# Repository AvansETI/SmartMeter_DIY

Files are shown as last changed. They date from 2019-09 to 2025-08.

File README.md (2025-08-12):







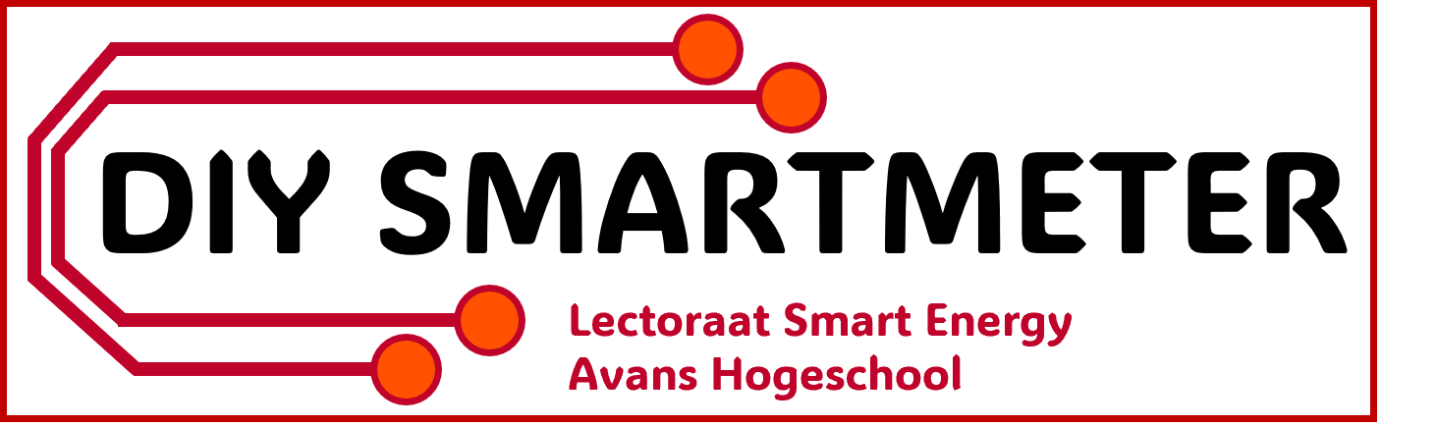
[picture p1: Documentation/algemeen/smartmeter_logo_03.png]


Bij het lectoraat Smart Energy, onderdeel van het Centre of Expertise Materialen en Energietransitie (MNEXT) van Avans Hogeschool te Breda, is een goedkoop en eenvoudig in elkaar te zetten do-it-yourself (DIY) kit(je) ontwikkeld, waarmee de slimme energiemeter thuis kan worden uitgelezen. Het kitje bestaat uit een printplaat, een minicomputer en wat losse elektronicacomponenten. Het in elkaar solderen, configureren en thuis aansluiten op de slimme energiemeter is een eenvoudige klus.

Dit inititief is ontstaan binnen de onderzoekslijn Meten & Weten. Het is belangrijk om meer inzicht te krijgen in het energieverbruik van het eigen huishouden. Door dit kitje kunnen consumenten en bedrijven inzicht krijgen in hun eigen energieverbruik.

Het doel van dit project is informatie te verzamelen van  veel aangesloten slimme meters ter ondersteuning van onderzoek en onderwijs. Alle verzamelde informatie is  moeilijk herleidbaar tot personen en/of locaties. De verzamelde informatie is openbaar om de energietransitie te ondersteunen.

Doe jij ook mee?

## Quick start
Heb je jouw DIY Smartmeter kitje al bemachtigd? Kijk dan op de [wiki](https://github.com/AvansETI/SmartMeter_DIY/wiki). Hier kan je de bouwhandleiding vinden voor het solderen van de printplaat én het uploaden van de firmware. Neem contact op met het lectoraat om in bezit te komen van dit gave kitje. Zie hieronder wat belangrijke links die je kan gebruiken.

* Wiki: [https://github.com/AvansETI/SmartMeter_DIY/wiki](https://github.com/AvansETI/SmartMeter_DIY/wiki)
* Source: [https://github.com/AvansETI/SmartMeter_DIY](https://github.com/AvansETI/SmartMeter_DIY)
* Lectoraat Smart Energy: [https://www.avans.nl/onderzoek/expertisecentra/mnext/lectoraten/smart-energy](https://www.avans.nl/onderzoek/expertisecentra/mnext/lectoraten/smart-energy)

## Meedoen
Niet alleen wij hebben goede ideeën. Jij kan ook meedoen. Heb je een leuk idee dan kan je dat via de issues dat kenbaar maken. Aan zowel de hardware en software kan je werken. Voor meer informatie zie [wiki](https://github.com/AvansETI/SmartMeter_DIY/wiki/8.-Contribute-to-the-software).

## Licentie
Alle documenten, hardware, software en documentatie zijn beschikbaar onder de [MIT-licentie](LICENSE.txt).

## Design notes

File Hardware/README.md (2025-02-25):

# SmartMeter Hardware

This directory contains all the versions we have created for this project. The hardware
is designed using KiCAD (https://www.kicad.org/) and the whole project is put on Git. It
is also possible to use the gerber files only to create your own version of the SmartMeter.

## Requirements

The hardware has been created with the following requirements:
1. It needs to be soldered by everyone!
2. All components should be through-the-whole.
3. The hardware will be provided as do-it-yourself kit.
4. It should support different type of SmartMeters P1-port with varying versions.

## Version 1

The first version of the SmartMeter. It contains some errors that neede to be fixed.

## Version 2

The second version fixed the errors.

## Version 2.1

This version supports the newest SmartMeter version. With this version is it possible to use
5V power from the SmartMeter. No need anymore to use an adapter. Furthermore, if you have an
electric vehicle, it can be connected to the hardware as well.

## Some notes

Make sure you use the newest version if you create your own version.

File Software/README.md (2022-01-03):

# SmartMeter Software

You can find here the firmware for the SmartMeter project. It uses a Wemos D1 mini lite
(https://www.wemos.cc/en/latest/d1/d1_mini_lite.html). Note that only the last version is
available that is used by the hardware version 2 and 3.

## sm-esp8266

This software is created using the Arduino IDE (https://www.arduino.cc/en/software). After
installing the IDE you need to add the ESP8266 boards. You can find a tutorial here: 
https://siytek.com/wemos-d1-mini-arduino-wifi/. Furthermore, you need to install some 
libraries:
- Install library WiFiManager by tablatronics: https://github.com/tzapu/WiFiManager
- Install library JsonArduino by Banoit Blanchon: https://arduinojson.org/?utm_source=meta&utm_medium=library.properties

when you are finished, you can compile and upload the sketch. In the case, you like more functionality
you can create the software yourself. We appreciate contribution by pull requests! You can become
part of the project as well.

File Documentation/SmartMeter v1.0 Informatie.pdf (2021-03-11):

## Expertisecentrum Technische Innovatie

## Lectoraat Smart Energy

# SMARTMETER

https://github.com/AvansETI/SmartMeter_DIY

Bij het Expertisecentrum Technische Innovatie (ETI) van Avans Hogeschool te Breda is een goedkope en makkelijk in elkaar te zetten do-it-yourself (DIY) kit(je) ontwikkeld waarmee de slimme energiemeter thuis kan worden uitgelezen. Het kitje bestaat uit een printplaat, een minicomputer en wat losse elektronica componenten. Het in elkaar solderen, configureren en thuis aansluiten op de slimme meter is een eenvoudige klus.

Het doel van dit alles is informatie uit veel aangesloten slimme meters te verzamelen. Deze informatie kan dan worden gebruikt in onderzoek en onderwijs. Alle verzamelde informatie is heel, heel moeilijk herleidbaar tot personen en/of locaties, hierover later meer. Alle verzamelde informatie is openbaar.

Avans Hogeschool en ETI nodigen iedereen uit om mee te doen in dit experiment. Voor de bouwhandleiding klik hier. (https://github.com/AvansETI/SmartMeter_DIY/wiki/Bouwhandleiding-van-de-DIY-Smart-Meter-kit)

SmartMeter specificatie
- Wemos D1 mini pro
- Smartmeter P1 interface
- Makkelijk te solderen

Werking
Het printplaatje is niets anders dan een interface die aangesloten wordt op de datapoort van een slimme meter. Deze poort heet ook wel de P1 poort. De minicomputer op het printplaatje zet P1 poort informatie om naar een internetprotocol. Bij Avans Hogeschool wordt deze

informatie in een database opgeslagen. De
minicomputer | is | met | het | internet
verbonden via de draadloze WiFi thuis.

Het printplaatje wordt gevoed met een standaard telefoonoplader. Het printplaatje wordt op de slimme meter aangesloten met
een | standaard | (ouderwetse) | vaste-
telefoon-kabeltje.

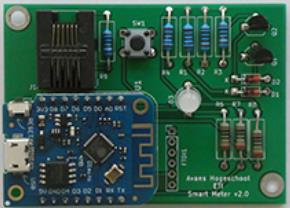
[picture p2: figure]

De informatie uit de P1 poort bevat
informatie | over | het | elektriciteit- | en
(meestal) aardgasverbruik. Oudere meters verversen deze infomatie elke 10 seconden,
recentere | meters | elke | seconde. | Het
printplaatje beperkt dit tot 1 bericht per 30 seconden. Per dag wordt ongeveer 2.5 Mbyte aan data verstuurd, dit is te vergelijken met een lage resolutie foto of een mp3 song.

Data
Elke minicomputer heeft een uniek nummer (Avans noemt dit een signature), Avans kan en wil dit nummer niet (vooraf) weten! De informatie uit jouw slimme meter is van jou maar door deze te delen kunnen studenten aan slimme toepassingen werken. De informatie uit de slimme meter wordt samengevoegd met het unieke nummer en verstuurd naar de Avans database. De verzonden informatie ziet er als volgt uit:

{"datagram": {
"p1": "/XMX5LGBBF...05FD\r\n",

"s1": {
"unit": "W",
"value": 0 },
"signature": "00000000d926eb43", "s0": {
"unit": "W",
"value": 0 } }
}

Onderwijs
Studenten gebruiken de SmartMeter om
een | Internet-ofThings | applicatie | te
realiseren. Hierbij wordt software voor de SmartMeter ontwikkeld, maar ook een back-end, database en front-end.

Onderzoek
Met de SmartMeter is het mogelijk op een
eenvoudige | wijze | gegevens | uit | een
smartmeter te halen en door te sturen naar
een | centrale | database. | Binnen | de
onderzoeken van het expertisecentrum wordt deze hardware gebruikt.

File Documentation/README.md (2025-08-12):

# Documentatie
De documentatie van de DIY Smartmeter kan je vinden op de [wiki](https://github.com/AvansETI/SmartMeter_DIY/wiki). Deze directory bevat alle bestanden en plaatjes die nodig zijn voor de wiki of andere markdown bestanden.

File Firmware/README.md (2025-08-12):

# SmartMeter Software

You can find here the firmware for the SmartMeter project. It uses a Wemos D1 mini lite
(https://www.wemos.cc/en/latest/d1/d1_mini_lite.html). Note that only the last version is
available that is used by the hardware version 2.0 and 2.1.

## ArduinoSketch / sm-esp8266

This software is created using the Arduino IDE (https://www.arduino.cc/en/software). After
installing the IDE you need to add the ESP8266 boards. You can find a tutorial here: 
https://siytek.com/wemos-d1-mini-arduino-wifi/. Furthermore, you need to install some 
libraries:
- Install library WiFiManager by tablatronics: https://github.com/tzapu/WiFiManager
- Install library JsonArduino by Banoit Blanchon: https://arduinojson.org/?utm_source=meta&utm_medium=library.properties
- Install library pubsubclient by Nick O'Leary: https://github.com/knolleary/pubsubclient

when you are finished, you can compile and upload the sketch. In the case, you like more functionality
you can create the software yourself. We appreciate contribution by pull requests! You can become
part of the project as well.

This project is actively maintained, see the release for the latest updates

## Functionality and services
The firmware implements the functionality to read the P1 messages from the Smart Meter that is connected and delivers some services to your home network.

### mDNS / Multicast DNS
The DIY Smartmeter serves a mDNS server in order to easily find your DIY Smartmeter that is connected to your local network. It uses multicast IP-addresses to find out the IP-address and the services running by the DIY Smartmeter. To check if it is working, you can easily type in your browser [http://diy_smartmeter.local](http://diy_smartmeter.local). You will see the dashboard that is published by the DIY Smartmeter.

### HTTP Dashboard
The HTTPS dashboard that is pusblished by the DIY Smartmeter, shows your actual energy consumption and production. Note that this webpage can be easily hosted by the DIY Smartmeter, while most of the code is downloaded from the github repo. In order to see this dashboard, you can type in your browser: [http://diy_smartmeter.local](http://diy_smartmeter.local). The image below is on example of the dashboard.

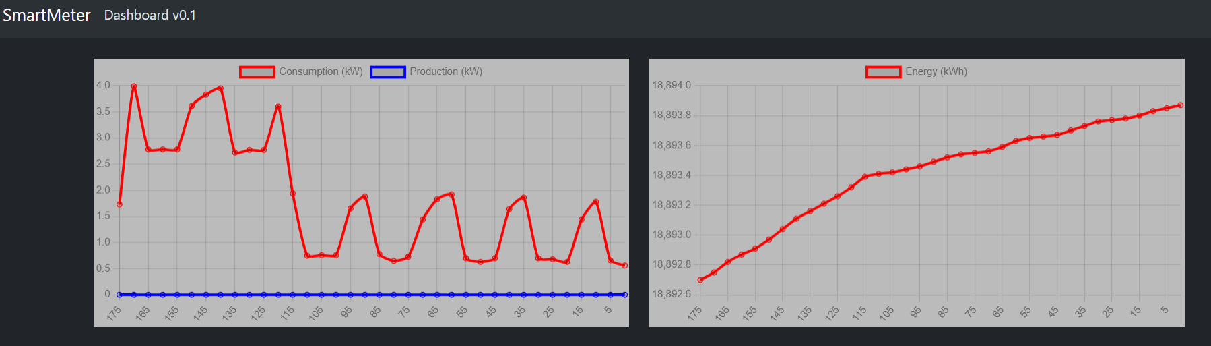
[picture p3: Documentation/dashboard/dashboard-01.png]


The following endpoints are served by the web server:
- /: The root of the web page that servers the dashboard.
- /data: The data endpoint that serves the energy consumption and production in JSON format.

Note, that memory is limited on the DIY Smartmeter, so not many data history is available in the dashboard. For more information of all your data points, you can check the public research server.

### P1 data server
On port 3141 the DIY Smartmeter is exposing a data server that sends raw P1 messages that are received from your Smartmeter. Note that the clients that can be connected are limited. Default two clients are able to connect. If too many clients are connected you will receive ```DIY Smartmeter P1 - too many clients connected```. So, it will be clear!

When connected you will get first a header message telling that you are connecter with the DIY Smartmeter P1 server. After that you will receive the raw P1 messages when it is received from the Smart Meter that is connected. Below an example with one raw P1 message:
```
DIY Smartmeter P1\n
/Ene5\\T211 ESMR 5.0\r\n\r\n1-3:0.2.8(50)\r\n0-0:1.0.0(250812225130S)\r\n0-0:96.1.1(*****************ID***************)\r\n1-0:1.8.1(012127.922*kWh)\r\n1-0:1.8.2(006766.244*kWh)\r\n1-0:2.8.1(003532.249*kWh)\r\n1-0:2.8.2(009276.445*kWh)\r\n0-0:96.14.0(0001)\r\n1-0:1.7.0(00.610*kW)\r\n1-0:2.7.0(00.000*kW)\r\n0-0:96.7.21(00017)\r\n0-0:96.7.9(00007)\r\n1-0:99.97.0(2)(0-0:96.7.19)(230621102410S)(0000004757*s)(221007100958S)(0000024711*s)\r\n1-0:32.32.0(00002)\r\n1-0:52.32.0(00002)\r\n1-0:72.32.0(00004)\r\n1-0:32.36.0(00000)\r\n1-0:52.36.0(00000)\r\n1-0:72.36.0(00000)\r\n0-0:96.13.0()\r\n1-0:32.7.0(228.0*V)\r\n1-0:52.7.0(230.0*V)\r\n1-0:72.7.0(228.0*V)\r\n1-0:31.7.0(001*A)\r\n1-0:51.7.0(001*A)\r\n1-0:71.7.0(003*A)\r\n1-0:21.7.0(00.226*kW)\r\n1-0:41.7.0(00.127*kW)\r\n1-0:61.7.0(00.255*kW)\r\n1-0:22.7.0(00.000*kW)\r\n1-0:42.7.0(00.000*kW)\r\n1-0:62.7.0(00.000*kW)\r\n!85FE\r\n
```

This service can be used for example:
1. To connect the DIY Smartmeter to your Home Assistant, see for more information the [wiki](https://github.com/AvansETI/SmartMeter_DIY/wiki/7.-Using-Home-Assistant-for-monitoring-the-P1-meter.). 
2. You can use this also for your own software implementation. An Python example is available that connects to the service and prints the P1 messages received: [p1dataclient.py](https://github.com/AvansETI/SmartMeter_DIY/blob/master/Software/p1dataclient.py)
3. You can use the P1 Extender to simulate your Smartmeter at home at a remote place, for example a electric car charger. For more information see [P1-Extender](https://github.com/macsnoeren/P1-Extender).

## MQTT client
MQTT client is used to connect to the research MQTT server and share the Smart Meter P1 data that is received. This data is publically available and used for research and eduacation.

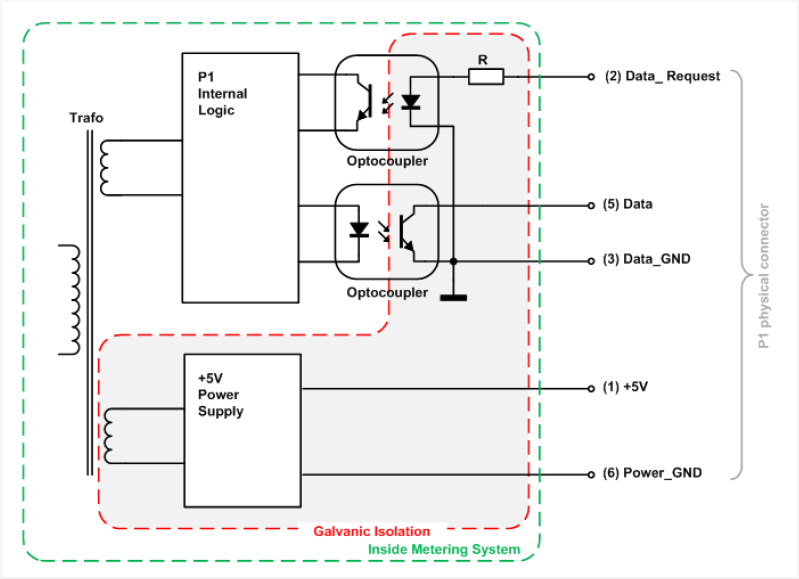
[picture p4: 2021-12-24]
Documentation/smartmeter/ESMRv5.0-P1-schematic.png

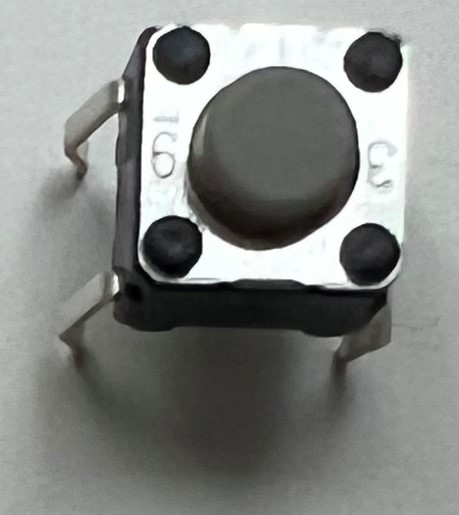
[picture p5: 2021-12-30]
Documentation/bouwhandleiding/stap_12.png

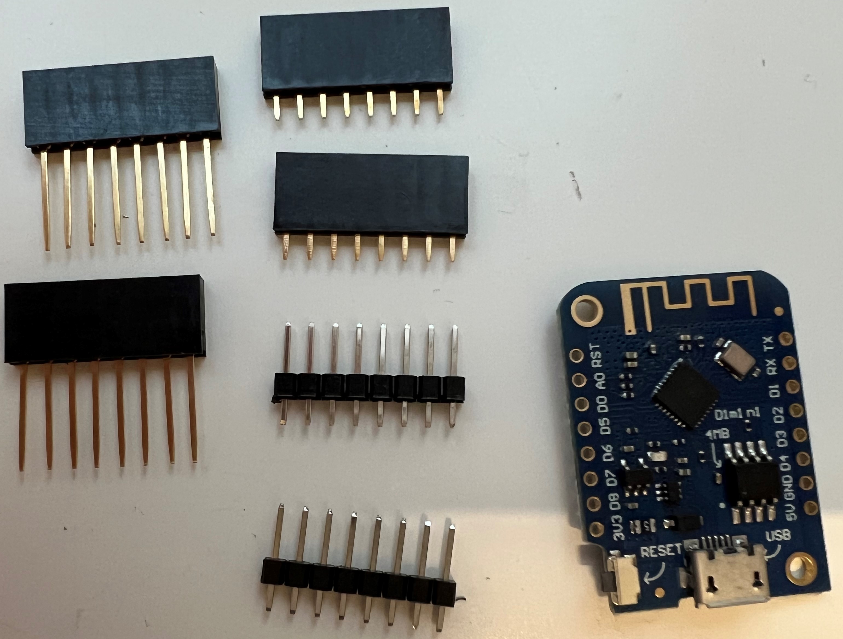
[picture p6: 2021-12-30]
Documentation/bouwhandleiding/stap_33.png

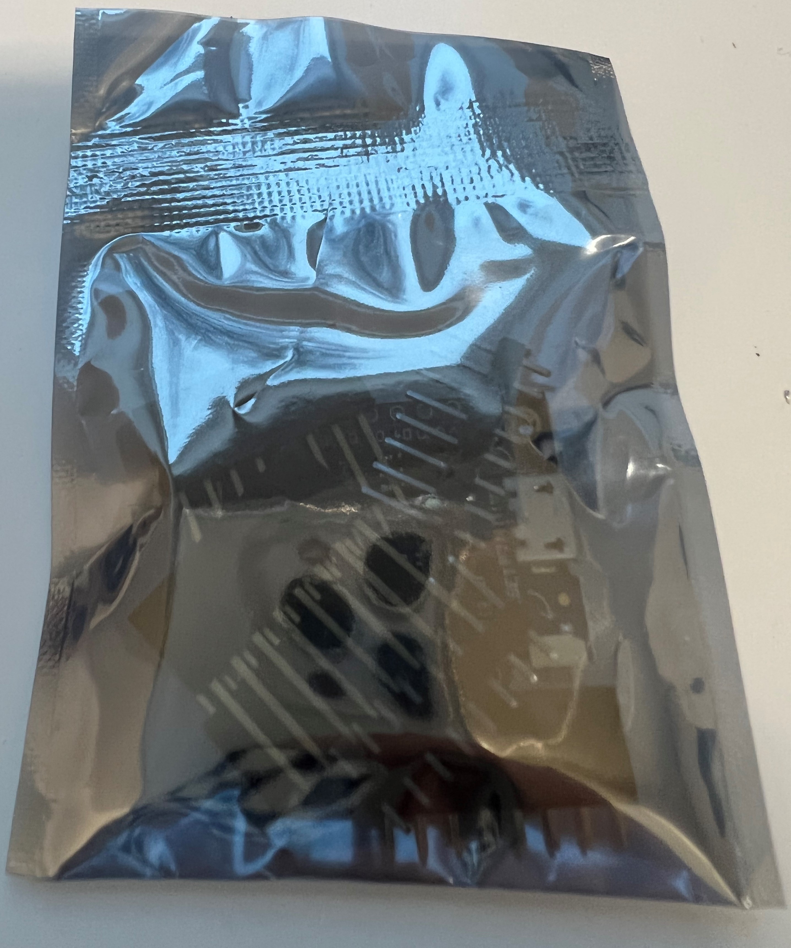
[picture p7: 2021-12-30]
Documentation/bouwhandleiding/stap_31.png

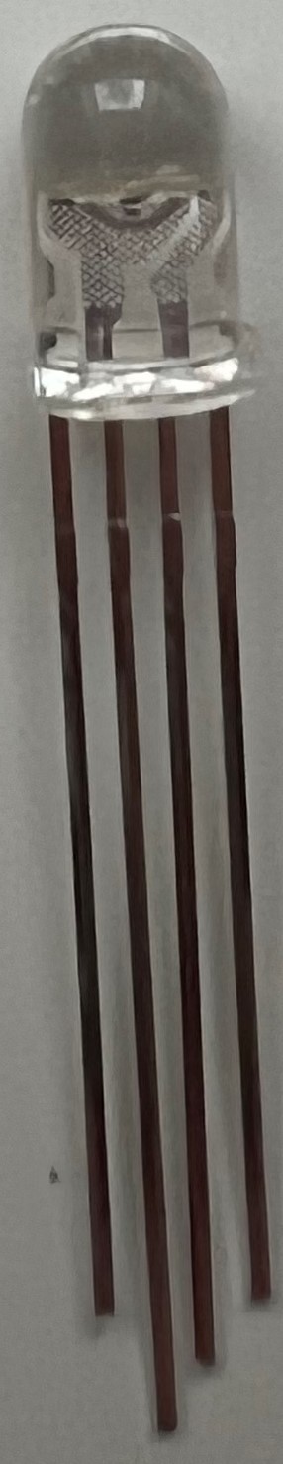
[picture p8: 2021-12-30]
Documentation/bouwhandleiding/stap_14.png

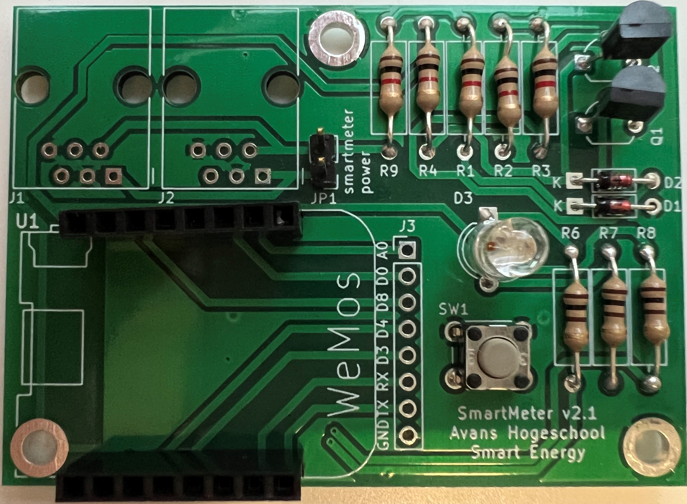
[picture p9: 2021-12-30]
Documentation/bouwhandleiding/stap_35.png

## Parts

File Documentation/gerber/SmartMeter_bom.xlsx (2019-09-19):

BOM Smart Meter
Expertisecentrum Technische Innovatie
Lectoraat Smart Energy
Qty | Value | Farnell Code
60 | 1N4148 | 2889103
30 | RGB Color Led | Kiwi: ADA-302
30 | RJ12 | 2135977
60 | BC547 | 1574381
90 | 100Ω | 9339043
120 | 1kΩ | 9339051
30 | Tactile Pushbutton | 1829495
30 | WeMos D1 Mini | [Waar Bestellen?]
30 | Kabel RJ12 - > RJ12 | 2070344
30 | Plastic zakje voor onderdelen + pcb | Nog voorradig

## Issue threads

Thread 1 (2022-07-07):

Handleiding om software op de Wemos te zetten

macsnoeren, 2022-07-07:
Op dit moment is het bouwen uitgebreid besproken. Echter worden de kitjes zonder firmware geleverd. Deze dient er dan ook nog opgezet te worden. Hiervoor hebben we ook een handleiding nodig.

macsnoeren, 2022-10-06:
Idee is om een hex file beschikbaar te stellen en een programma zoals: https://www.esp8266.com/viewtopic.php?p=90891

macsnoeren, 2024-11-09:
Deze is inmiddels opgelost door een browser-based uploader beschikbaar te stellen. Zie handleiding.

Closed 2024-11-09.

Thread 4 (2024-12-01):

Clarify MQTT datagram creation

macsnoeren, 2024-12-01:
Why are these values inserted in here? Can these be removed? (line 916 in ino firmware)

```
    JsonObject s0 = datagram.createNestedObject("s0");
    s0["unit"] = "W";
    s0["label"] = "e-car charger";
    s0["value"] = 0;

    JsonObject s1 = datagram.createNestedObject("s1");
    s1["unit"] = "W";
    s1["label"] = "solar panels";
    s1["value"] = 0;
```

dkroeske, 2024-12-01:
No, there are for pulse count measurements. This is work in progress

macsnoeren, 2024-12-01:
Oké, so not in use for know, but something you are adding later. Thanks! I will put the comment in and keep it.

Closed 2025-02-01.

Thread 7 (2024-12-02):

Update hardware to ESP32(S2?)

macsnoeren, 2024-12-02:
In order to make use of the Github.com to collaborate on the smartmeter. There is an idea and @dkroeske is already started with this development. I am curious what you are planning.

macsnoeren, 2025-03-29:
@dkroeske Are you already able to push a new firmware to the repo? To development or a separate branch dev/sm-esp32s2 or so?

macsnoeren, 2025-07-27:
Hi @dkroeske, can you push your new development of the new firmware for the new hardware to the branch of this issue "7-update-hardware-to-esp32s2"? Then we can work on it as community, see https://github.com/AvansETI/SmartMeter_DIY/wiki/8.-Contribute-to-the-software. Thanks :).

macsnoeren, 2025-08-15:
Currently, the current firmware has been made available for the ESP32(S2) as well. It tested and it works as expected. The same firmware can be compiled for the ESP8266 and ESP32(S2) at this moment. Some more test is required, before it will be merged into the main branch. From this basis, we would like to add new functionality that is possible when the ESP32S2 is used. For example security. However, in order to implement the appropriate security functionality, we need to create a threat model and perform a risk assessment, while it is not fully clear what the risks are. While the data is publicly available encryption would be not a good approach possibly. Removing the equipment ID could be a better approach, while this is not used within the research for example. What is required to implement the correct security measures, will be extracted from the threat model and risk analysis.

macsnoeren, 2025-08-16:
While both @abroeders and myself do not hear anything from the new firmware, we changed the firmware so it compiles also for the ESP32S2. Furthermore, the functionality to anonimize the P1 data send to the MQTT server and to the TCP clients has been added. This way the data does not have any relation with persons. @abroeders also has more wishes for the new firmware, so we have created an issue to work on the new release v2.0 of the software that can run on both ESP8266 and ESP32S2. See. https://github.com/AvansETI/SmartMeter_DIY/issues/37. Please note, that we would like to collaborate on this project using Github. This is described in the Wiki. If you also want to add functionality to the new release, it starts by describing and discussing and creating a branch to do so. For now, I close this issue, while we want to start working on the new firmware via the issue https://github.com/AvansETI/SmartMeter_DIY/issues/37. Thanks.

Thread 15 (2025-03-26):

Update the documentation of the repository

macsnoeren, 2025-03-26:
The repository still contain old information and no information on the enhancements of the TCP/IP server and the web server.

abroeders, 2025-07-26:
Added quick setup instructions for home assistant

macsnoeren, 2025-08-12:
Ik heb de hoofdpagina (README.md) aangepast naar de laatste stand. Hiervoor heb ik ook een DIY SmartMeter logo gemaakt en gebruikt. https://github.com/AvansETI/SmartMeter_DIY/tree/15-update-the-documentation-of-the-repository.

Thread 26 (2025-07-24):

New socketserver failes as MQTT becomes inactive.

abroeders, 2025-07-24:
Not exactly sure — I'm on vacation and away from home.
Symptoms: The servers in the SEnDLab are down. I guess someone turned off the mains again :-(.
Now, the Home Assistant plugin "DSMR Smart Meter" can't establish a socket connection to port 3141 anymore. The P1 meter is still connected to the Wi-Fi network.

When manually disconnecting the Wi-Fi session, the connection to the network re-establishes, but the server socket on port 3141 remains unavailable.

macsnoeren, 2025-07-25:
Will check it, possibly the state machine blocks this, while it wants first to have an active MQTT connection.

macsnoeren, 2025-07-26:
When the MQTT server is disconnected, the code in the main loop contains a 400ms delay, that most likely causes the problems to handle the requests for the HTTP, MDNS and TCP/IP data server. I have now proposed a fix that waits 5 seconds to retry the connection of the MQTT without delaying the other functionality. During connection the led is flashed that takes 150ms delay and the connection itself (when the server is not available) will also introduce some delay most likely. I am not able to test it at this moment. If possible, you could try whether the new firmware on the selected branch (26-new-socketserver-failes-as-mqtt-becomes-inactive) is working.

When we would like to have totally no delays for the different functionality, it is required to redesign part of the application. If we would like to do so, it is maybe nice to create also a kind of wish/function list to create version 2. I also do not know how far the development is for the new Wemos S2 mini hardware.

macsnoeren, 2025-07-26:
Tested the solution and it works. However, every 10 seconds the reconnection to the MQTT server takes a bit of time. Resulting into a little delay in the response of the HTTP and TCP server as expected. This solution can be pushed to main. Furthermore, added more textual improvements to the current firmware.

Closed 2025-07-26.

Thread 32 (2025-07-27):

Adapt firmware so it can be compiled for ESP8266 and ESP32S2

macsnoeren, 2025-07-27:
A first step to adapt the firmware, so it can be compiled for both the Wemos D1 mini lite (ESP82660) and the Wemos S2 mini (ESP32S2). We would like to have backwards compability and be able to start utilizing all the great stuff that comes with the new ESP32S2.

macsnoeren, 2025-08-13:
Testing results:
- Led works
- WifiManager works

macsnoeren, 2025-08-14:
All functionality is working correctly, only the MQTT connection cannot be tested due to a down sendlab. New version will be installed at my place and tested for longer time.

macsnoeren, 2025-08-14:
```
Sketch uses 1121210 bytes (85%) of program storage space. Maximum is 1310720 bytes.
Global variables use 66872 bytes (20%) of dynamic memory, leaving 260808 bytes for local variables. Maximum is 327680 bytes.
```

macsnoeren, 2025-08-15:
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

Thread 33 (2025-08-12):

Personally identifiable information

macsnoeren, 2025-08-12:
As we do not want to store personally identifiable information (PII), we should replace all equipment IDs (0-n:96.1.1) of the P1 message to a own created ID. The equipment IDs are at the energy distribution company (DSO) known and they are able to connect it to a real customer/person. If we change these IDs to our own ID, it is not possible anymore that the DSO is able to connect it to a real customer. At this moment, we sent these IDs over the MQTT server to the research lab. We can user the already created a unique ID for each DIY Smartmeter for this purpose. Or we can just insert a fake number and skip the processing at the research computers.

For our research this information is not required and therefore we should remove it or insert a fake number if that is easier. Definitely not store at nor send it to our research database.  See below example of a P1 message. If we do this, we do not have any possible connections with real persons/customers.

```
/Ene5\\T211 ESMR 5.0\r\n\r\n1-3:0.2.8(50)\r\n0-0:1.0.0(250812225130S)\r\n0-0:96.1.1(**EQUIPMENT-ID**)\r\n1-0:1.8.1(012127.922*kWh)\r\n1-0:1.8.2(006766.244*kWh)\r\n1-0:2.8.1(003532.249*kWh)\r\n1-0:2.8.2(009276.445*kWh)\r\n0-0:96.14.0(0001)\r\n1-0:1.7.0(00.610*kW)\r\n1-0:2.7.0(00.000*kW)\r\n0-0:96.7.21(00017)\r\n0-0:96.7.9(00007)\r\n1-0:99.97.0(2)(0-0:96.7.19)(230621102410S)(0000004757*s)(221007100958S)(0000024711*s)\r\n1-0:32.32.0(00002)\r\n1-0:52.32.0(00002)\r\n1-0:72.32.0(00004)\r\n1-0:32.36.0(00000)\r\n1-0:52.36.0(00000)\r\n1-0:72.36.0(00000)\r\n0-0:96.13.0()\r\n1-0:32.7.0(228.0*V)\r\n1-0:52.7.0(230.0*V)\r\n1-0:72.7.0(228.0*V)\r\n1-0:31.7.0(001*A)\r\n1-0:51.7.0(001*A)\r\n1-0:71.7.0(003*A)\r\n1-0:21.7.0(00.226*kW)\r\n1-0:41.7.0(00.127*kW)\r\n1-0:61.7.0(00.255*kW)\r\n1-0:22.7.0(00.000*kW)\r\n1-0:42.7.0(00.000*kW)\r\n1-0:62.7.0(00.000*kW)\r\n!85FE\r\n
```

What would we like to do?

macsnoeren, 2025-08-16:
ESP8266 built:
```
. Variables and constants in RAM (global, static), used 39276 / 80192 bytes (48%)
║   SEGMENT  BYTES    DESCRIPTION
╠══ DATA     1620     initialized variables
╠══ RODATA   7096     constants
╚══ BSS      30560    zeroed variables
. Instruction RAM (IRAM_ATTR, ICACHE_RAM_ATTR), used 61019 / 65536 bytes (93%)
║   SEGMENT  BYTES    DESCRIPTION
╠══ ICACHE   32768    reserved space for flash instruction cache
╚══ IRAM     28251    code in IRAM
. Code in flash (default, ICACHE_FLASH_ATTR), used 391228 / 1048576 bytes (37%)
║   SEGMENT  BYTES    DESCRIPTION
╚══ IROM     391228   code in flash
```

macsnoeren, 2025-08-16:
The functionality to anonomize the P1 datagram by zero all the equipment IDs have been implemented and tested on both ESP8266 and ESP32S2. As the above statement, the wish is to make more improvements for the coming release v2.0. So therefore this work has been merged into the new release branch https://github.com/AvansETI/SmartMeter_DIY/issues/37. The comment above will be transferred to the new release requirements as well. This issue will be closed.

Closed 2025-08-16.

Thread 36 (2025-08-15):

At startup default configuration parameters are loaded and not the ones stored in LittleFS

macsnoeren, 2025-08-15:
The configuration parameters at startup are always loaded with the default ones. It is expected that the values that are filled into the webpage, written to the LittleFS, are read by the firmware. This is not the case. See below the summary from the firmware after the first time the configuration is made. The correct values are shown that were filled in. In this case, I have filled in User and Pass in the MQTT values.
```
*wm:Connect to new AP [SUCCESS]
*wm:Got IP Address:
*wm:192.168.2.33
*wm:config portal exiting

************ DIY Smartmeter KIT********************
ESP32S2 info
	SDK Version     : v5.5-1-gb66b5448e0
	Core Version    : 3.3.0
	Core Frequency  : 240 Mhz
	Last reset      : SW_RESET
MQTT settings
	mqtt_username   : User
	mqtt_password   : Pass
	mqtt_id         : DIY-SMARTMETER-V2-A26DC7E6FC84
	mqtt_topic      : smartmeter/raw
	mqtt_remote_host: mqtt.sendlab.nl
	mqtt_remote_port: 11883
	IP address      : 192.168.2.33
	mqtt_anonimize_p1: YES
DSMR settings
	P1 Baudrate     : 115200 baud
mDNS
	mDNS URL        : diy_smartmeter.local
	Web server      : diy_smartmeter.local:80
	Data server     : diy_smartmeter.local:3141
***************************************************
```

After I pressed the reset button of the board, I get the below summary that holds the default values again. In this case, the smartmeter (not User) and se_smartmeter (not Pass).
```
*wm:connectTimeout not set, ESP waitForConnectResult...
*wm:AutoConnect: SUCCESS
*wm:STA IP Address: 192.168.2.33

************ DIY Smartmeter KIT********************
ESP32S2 info
	SDK Version     : v5.5-1-gb66b5448e0
	Core Version    : 3.3.0
	Core Frequency  : 240 Mhz
	Last reset      : POWERON_RESET
MQTT settings
	mqtt_username   : smartmeter
	mqtt_password   : se_smartmeter
	mqtt_id         : DIY-SMARTMETER-V2-A26DC7E6FC84
	mqtt_topic      : smartmeter/raw
	mqtt_remote_host: mqtt.sendlab.nl
	mqtt_remote_port: 11883
	IP address      : 192.168.2.33
	mqtt_anonimize_p1: YES
DSMR settings
	P1 Baudrate     : 115200 baud
mDNS
	mDNS URL        : diy_smartmeter.local
	Web server      : diy_smartmeter.local:80
	Data server     : diy_smartmeter.local:3141
***************************************************
```

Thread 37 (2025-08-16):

Release v2.0

macsnoeren, 2025-08-16:
While many updates and functions have been added to the software, we would like to create the next version. More improvements would be added to this release. These requirements will be added to this issue list. The requirements that are known are:
- Make firmware also compatible for the ESP32(S2) using the same firmware
- Add option to remove Personal Identifiable Information (PII) from the P1 datagram when send to MQTT server and/or TCP/IP data server.
- Naming convention improvement towards "DIY_SMARTMETER" and remove EMON naming.

macsnoeren, 2025-08-16:
@abroeders: Do we still need the old json structure with all the stub attributes like 's0' and 's1'. I think, as we make a complete new version (v2), we can use a single {"datagram": {"signature": "xxxxxx", "p1": "xxxxxxxxxx"}} structure. If we need more attributes later, we can add them at that time. For the privacy option, why use a fake number and not completely strip the "(0-n:96.1.1)" attributes from the telegram. I think there are some lightweighted limited regex libs for the ESP available to help replace those id's with an empty string.

macsnoeren, 2025-08-16:
> @abroeders: Do we still need the old json structure with all the stub attributes like 's0' and 's1'. I think, as we make a complete new version (v2), we can use a single {"datagram": {"signature": "xxxxxx", "p1": "xxxxxxxxxx"}} structure. If we need more attributes later, we can add them at that time. For the privacy option, why use a fake number and not completely strip the "(0-n:96.1.1)" attributes from the telegram. I think there are some lightweighted limited regex libs for the ESP available to help replace those id's with an empty string.

@abroeders the reason for a fake number (zeros) is that it is possible post processing entities will not brake when they somehow try to parse these id's. And it is easy to implement without the need for libs or complex code.

For me this is similar to remove it from the datagram. If deletion is required, I can implement it without the need of a regex library. Or as an extra option?

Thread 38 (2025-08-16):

Security discussion: With MQTT username and password someone could fake or pullute existing SmartMeter data

macsnoeren, 2025-08-16:
While the MQTT username and password (and the MQTT connection details) are known on the Github repo, DIY SmartMeter firmware and DIY SmartMeter configuration, someone could create an application and send fake data to the MQTT or send fake data for an already existing DIY SmartMeter to pullute the data.  Do we want to resolve this so only genuine DIY SmartMeters are able to connect? Do you see this also as a security risk?

macsnoeren, 2025-08-24:
One of the ideas:
1. Add to the configuration that the SmartMeter could register itself to the server, so the server is able to check the validity of the messages coming from this device
2. Registering of the SmartMeter will be done by ECDH Diffie-Hellman key exchange (later changed to post quantum encryption) to a new key exchange server. This key exchange server stores the shared key with the DIY_SMARTMETER id. When it is registered, it will never accept new registrations of the same device.
3. The parsing server is adapter, so it will communicate with the key exchange server to check whether the device id has been registered and whether the HMAC send by the device is correct. If so, the parser has validated that the device send the message.
4. If validated the data can be processed as normal and send to the database.

For post-quantum encryption we will implement a hybrid approach where the ESP uses ECDH and the server uses ML-KEM. This will lead to a quantum resistant situation, where AES256 is already sufficient.

macsnoeren, 2025-08-24:
If hash of the key is used to encrypt the hmac, than man-in-the-middle is also not possible. Therefore, there is no need for any TLS encryption of the server nor MQTT for data integrity.

macsnoeren, 2025-08-24:
```
Connection from ('86.85.186.155', 51301)
Sent ECDH public key to ('86.85.186.155', 51301)
Received client public key from ('86.85.186.155', 51301) with id DIY-SMARTMETER-V2--CD5173-1640D8
ECDH key exchange completed with ('86.85.186.155', 51301)
Shared key hash: 42731d177f5eb6d2
Full shared key (32 bytes): 9adcfd78aeb2eed73606ad35b9136a997e0e70dc83e219ace5ade65c5b92e08a
Successfully saved shared key!
```

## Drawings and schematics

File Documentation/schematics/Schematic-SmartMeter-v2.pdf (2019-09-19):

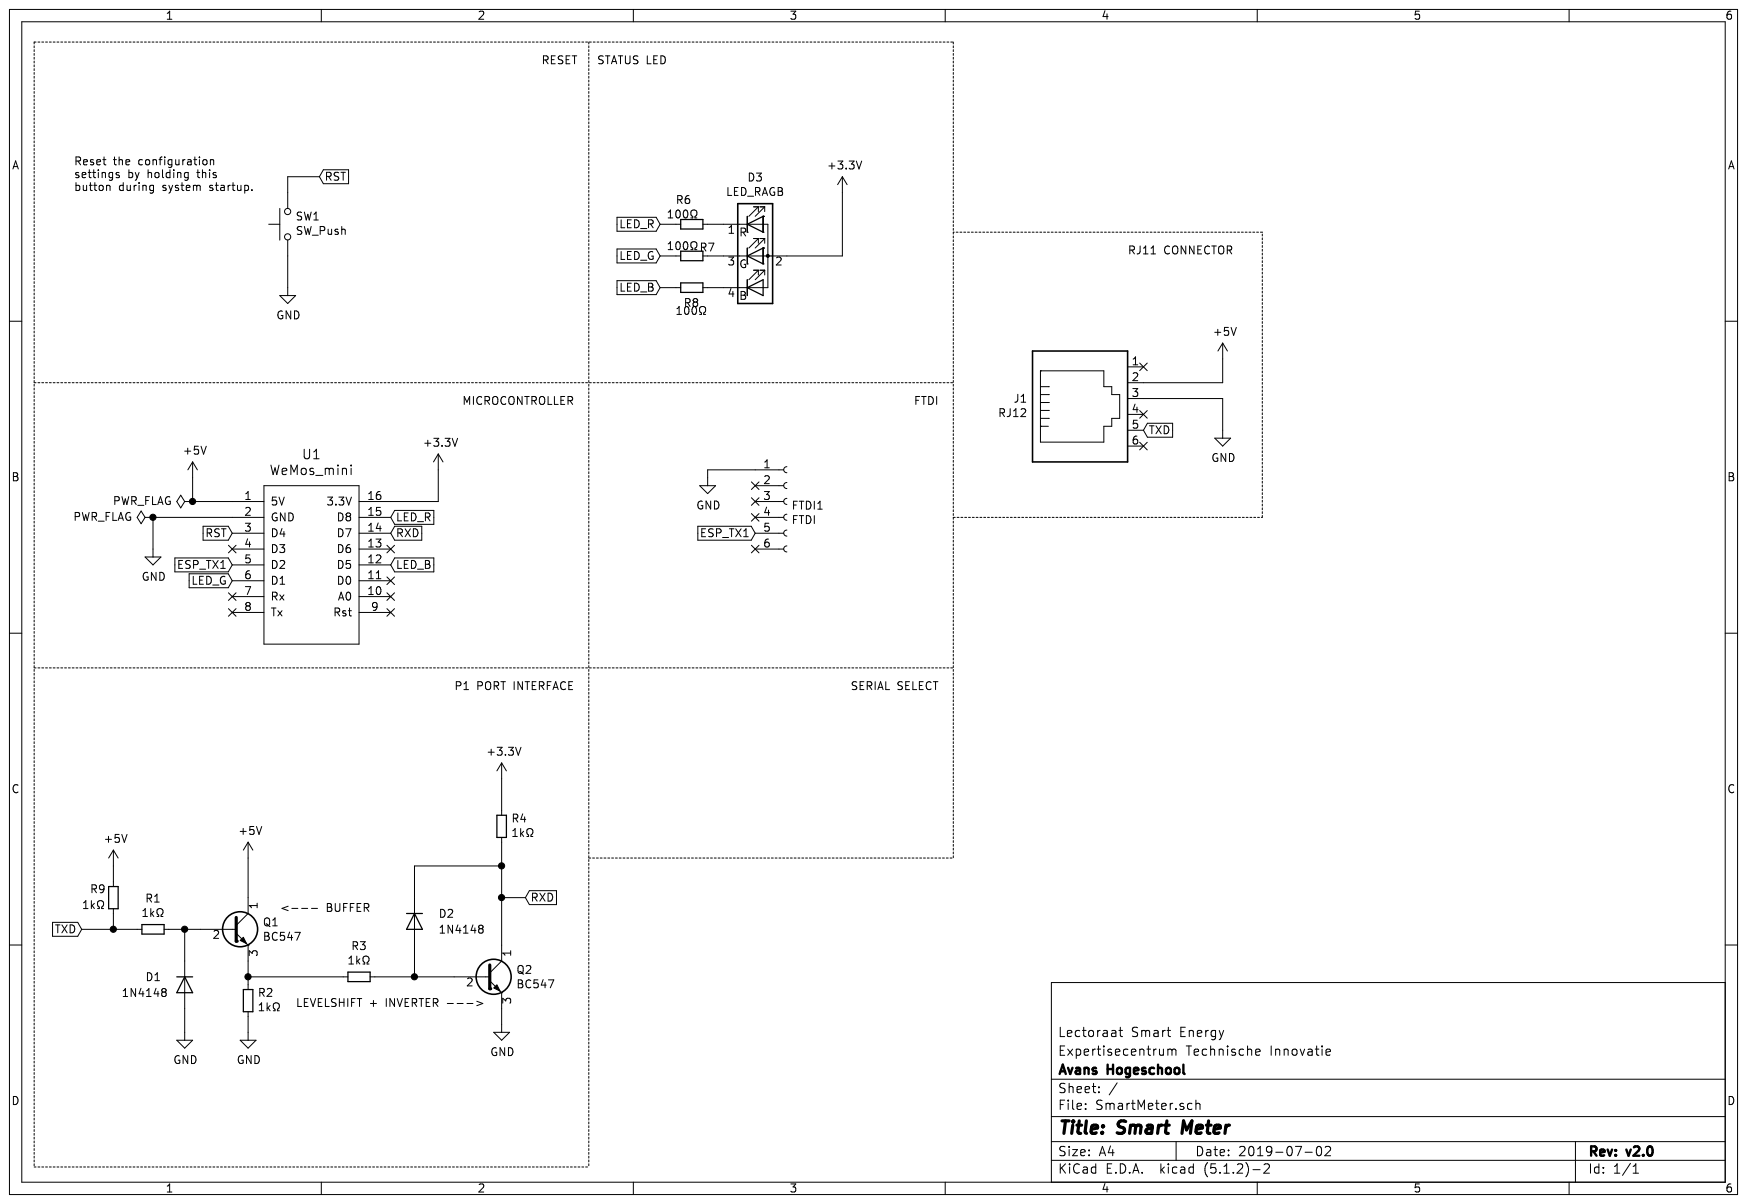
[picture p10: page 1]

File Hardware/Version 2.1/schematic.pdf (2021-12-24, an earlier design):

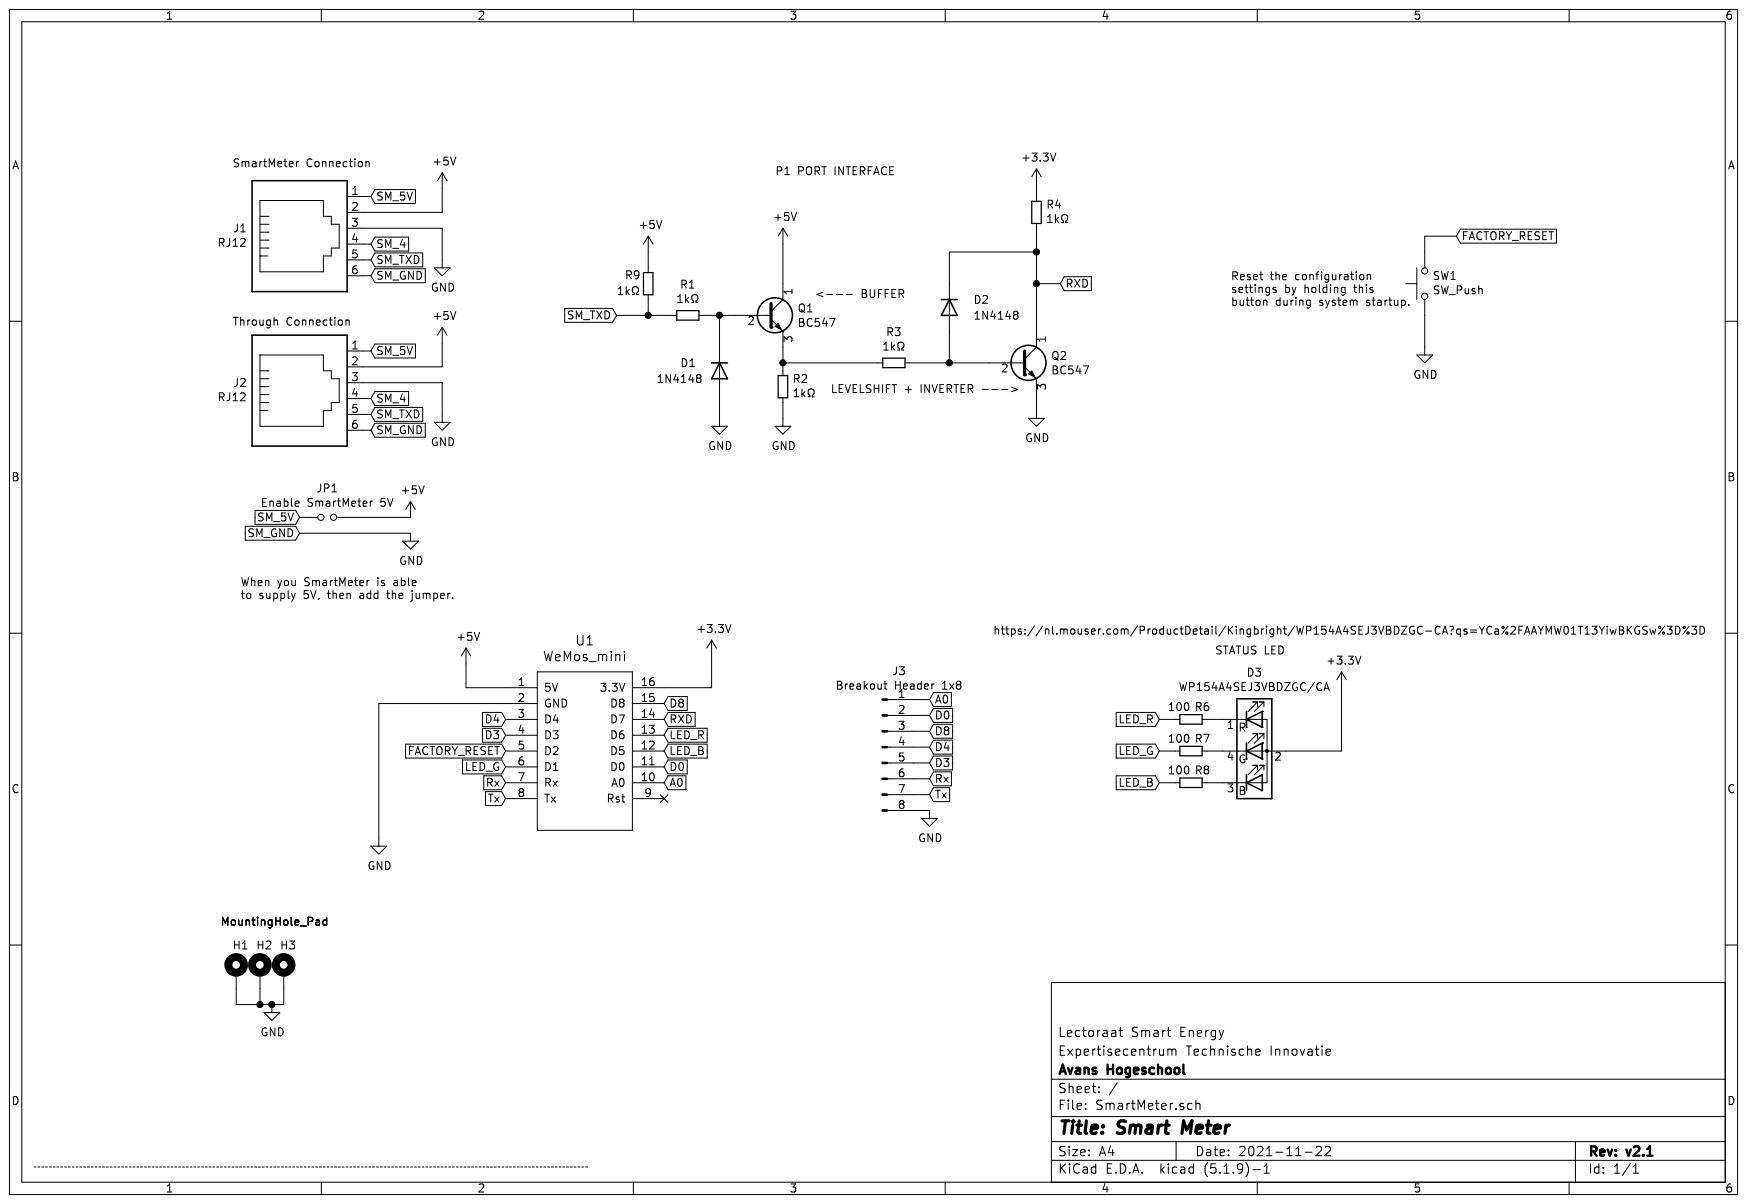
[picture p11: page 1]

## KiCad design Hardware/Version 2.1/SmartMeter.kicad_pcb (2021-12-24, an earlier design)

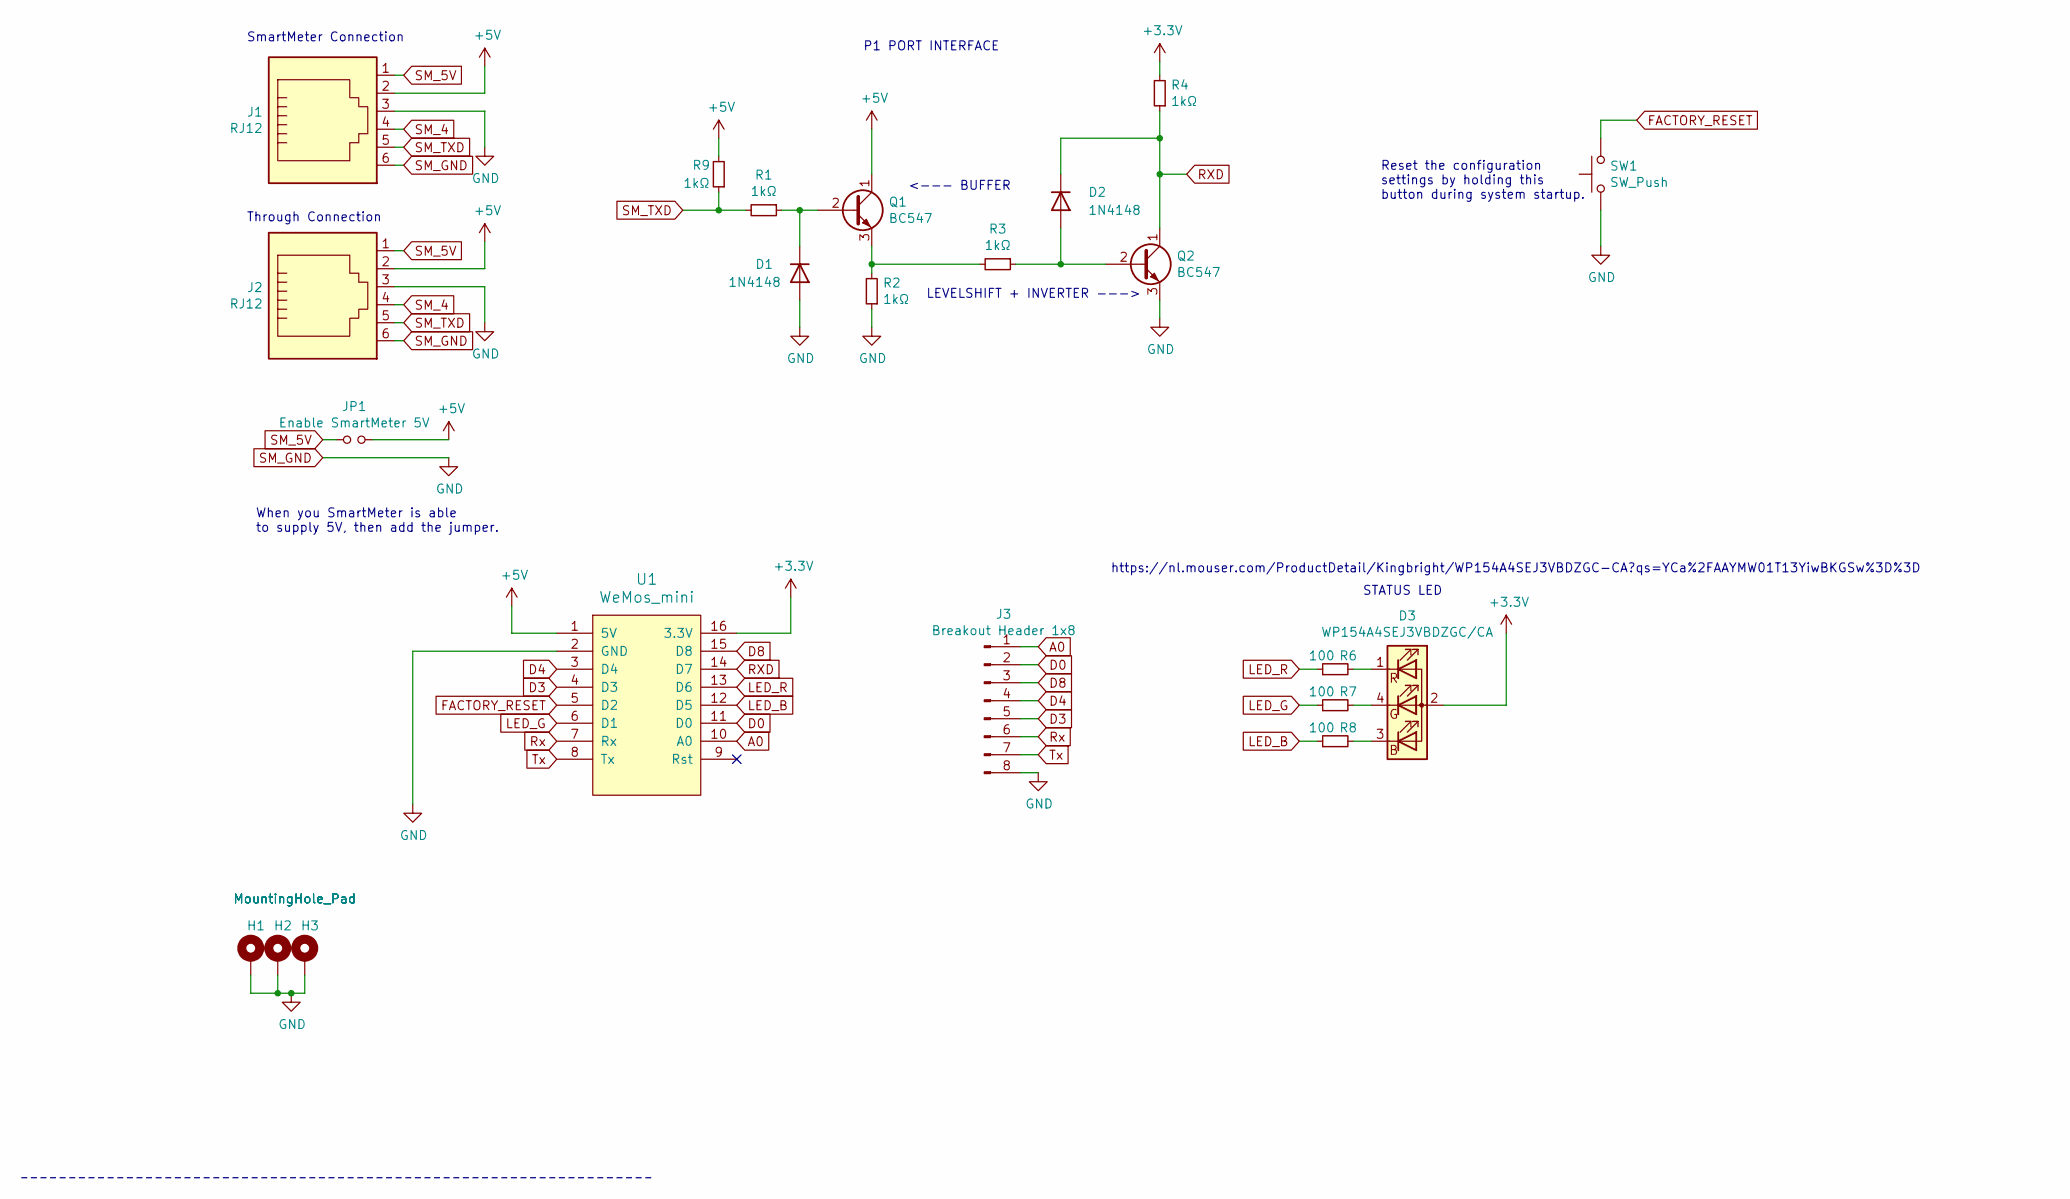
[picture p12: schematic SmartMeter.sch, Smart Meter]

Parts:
D1, D2: 1N4148; D_DO-35_SOD27_P7.62mm_Horizontal
D3: WP154A4SEJ3VBDZGC/CA; LED_D5.0mm-4_RGB_Wide_Pins
H1, H2, H3: MountingHole_Pad; MountingHole_3.2mm_M3_DIN965_Pad
J1, J2: RJ12; RJ12_Amphenol_54601
J3: Breakout Header 1x8; PinHeader_1x08_P2.54mm_Vertical
JP1: Enable SmartMeter 5V; PinHeader_1x02_P2.54mm_Vertical
Q1, Q2: BC547; TO-92_Wide
R1, R2, R3, R4, R9: 1kΩ; R_Axial_DIN0309_L9.0mm_D3.2mm_P12.70mm_Horizontal
R6, R7, R8: 100; R_Axial_DIN0309_L9.0mm_D3.2mm_P12.70mm_Horizontal
SW1: SW_Push; SW_PUSH_6mm
U1: WeMos_mini; D1-MINI

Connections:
+3V3: D3.2 (A), R4.2, U1.16 (3.3V)
+5V: J1.2, J2.2, JP1.2, Q1.1 (C), R9.2, U1.1 (5V)
A0: J3.1, U1.10 (A0)
D0: J3.2, U1.11 (D0)
D3: J3.5, U1.4 (D3)
D4: J3.4, U1.3 (D4)
D8: J3.3, U1.15 (D8)
FACTORY_RESET: SW1.2, U1.5 (D2)
LED_B: R8.1, U1.12 (D5)
LED_G: R7.1, U1.6 (D1)
LED_R: R6.1, U1.13 (D6)
unnamed: D1.1 (K), Q1.2 (B), R1.1
unnamed: D2.2 (A), Q2.2 (B), R3.1
unnamed: D3.1 (RK), R6.2
unnamed: D3.3 (BK), R8.2
unnamed: D3.4 (GK), R7.2
unnamed: Q1.3 (E), R2.2, R3.2
RXD: D2.1 (K), Q2.1 (C), R4.1, U1.14 (D7)
Rx: J3.6, U1.7 (Rx)
SM_4: J1.4, J2.4
SM_5V: J1.1, J2.1, JP1.1
SM_GND: D1.2 (A), H1.1, H2.1, H3.1, J1.3, J1.6, J2.3, J2.6, J3.8, Q2.3 (E), R2.1, SW1.1, U1.2 (GND)
SM_TXD: J1.5, J2.5, R1.2, R9.1
Tx: J3.7, U1.8 (Tx)

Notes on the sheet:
P1 PORT INTERFACE
Reset the configuration settings by holding this button during system startup.
<--- BUFFER
LEVELSHIFT + INVERTER --->
STATUS LED
SmartMeter Connection
Through Connection
When you SmartMeter is able to supply 5V, then add the jumper.
https://nl.mouser.com/ProductDetail/Kingbright/WP154A4SEJ3VBDZGC-CA?qs=YCa%2FAAYMW01T13YiwBKGSw%3D%3D

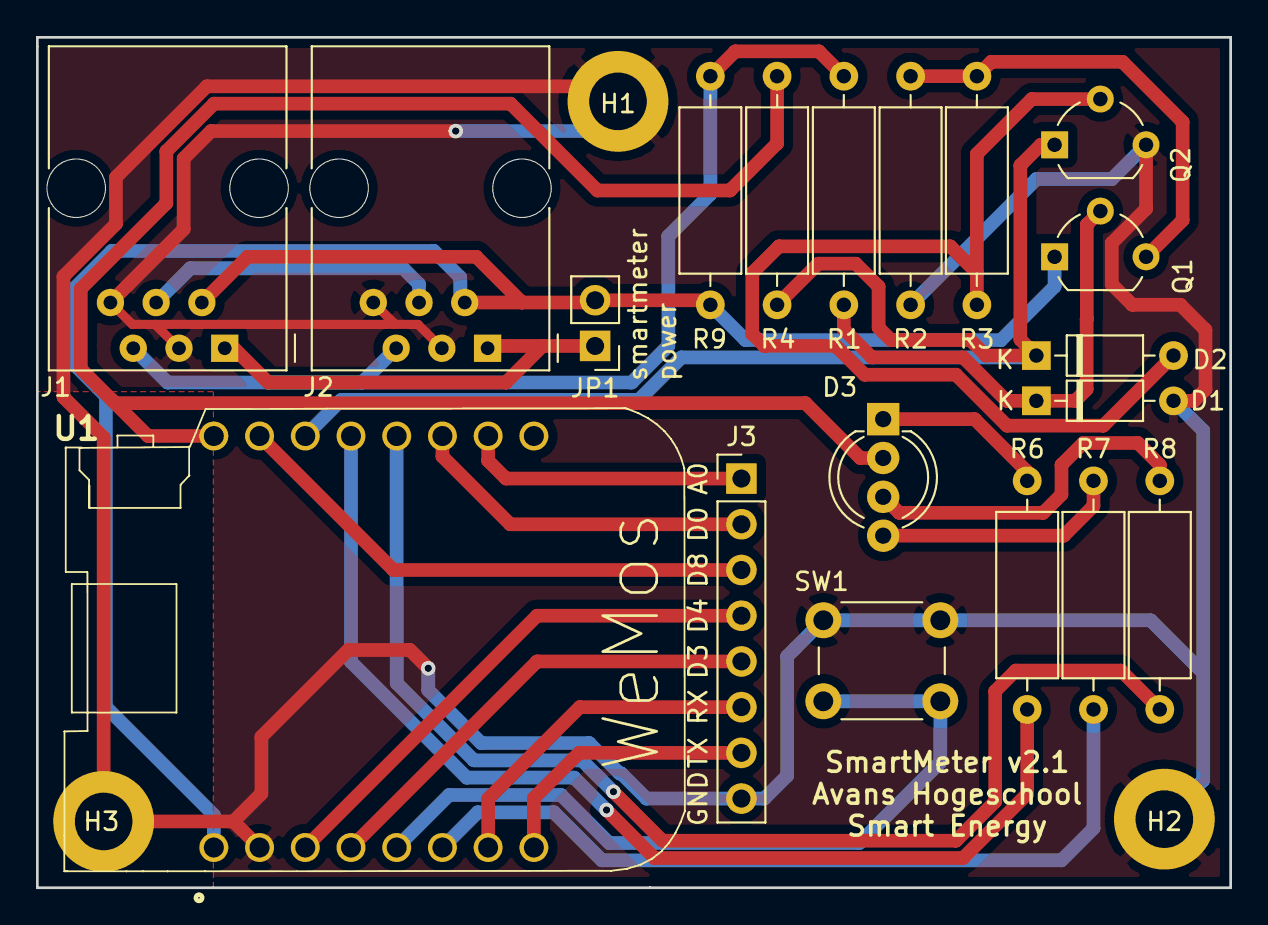
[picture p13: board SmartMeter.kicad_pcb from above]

Board: 2 copper layers, 66.3 x 47.2 mm, 22 parts (0 on the bottom side), 24 nets.

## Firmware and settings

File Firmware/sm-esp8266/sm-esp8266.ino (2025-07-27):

/*-------------------------------------------------------------------------
  The MIT License (MIT)
  Copyright © 2025 Avans Hogeschool Lectoraat Smart Energy
  
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
  -------------------------------------------------------------------------
  
  Arduino sketch to mqtt Dutch Smart Meter P1 datagrams.

  See for more information: https://github.com/AvansETI/SmartMeter_DIY.
  Flash latest firmware version for the Wemos D1 mini lite (ESP8266): https://avanseti.github.io/SmartMeter_DIY/.

  V1.0: Initial: dkroeske(dkroeske@gmail.com), august 2019
  V1.1: Reroute pinning PCB, updated bootsequence
  V1.2: Updated to latest version ArduinoJson library (feb 2020)
  V1.3: Updated to latest PubSubClient (jan 2021)
  V1.4: Changed server location (sendlab.nl), removed credentials
  V1.5: Added webserver to get insight into the smartmeter readings, added
        TCP/IP service (port 3141) to get actual P1 message and fixed mDNS
        so devices can be found by diy_smartmeter.local on your network (ms: jan 2025)
  V1.6: Migrated from SPIFSS (deprecated) to LittleFS and changed WiFiServer.availble (deprecated) to .accept. 
        Migrated ArduinoJSON 6 to 7: https://arduinojson.org/v7/how-to/upgrade-from-v6/
        Added extra information to serial about the mDNS service and updated libraries.
  V1.7: Improved TCP data server and added the configuration for more than one client to connect.

  Installation Arduino IDE:
  - How to get the Wemos installed in the Ardiuno IDE: https://siytek.com/wemos-d1-mini-arduino-wifi/
  - Install library WiFiManager by tablatronics: https://github.com/tzapu/WiFiManager
  - Install library JsonArduino by Banoit Blanchon: https://arduinojson.org/?utm_source=meta&utm_medium=library.properties
  - Install library knolleary/PubSubClient by Nick O'Leary: https://github.com/knolleary/pubsubclient
 
  Happy Coding
  -------------------------------------------------------------------------*/
#include <ESP8266WiFi.h>
#include <ESP8266WebServer.h>
#include <WiFiClient.h>
#include <WiFiManager.h>
#include <Ticker.h>
#include <ESP8266mDNS.h>
#include <ArduinoJson.h>
#include <LittleFS.h>
#include <Ticker.h>

#include "PubSubClient.h"

// Homeserver credentials
#include "MqttSendlab.h"

#define DEBUG

#ifdef DEBUG
 #define DEBUG_PRINTF(format, ...) (Serial1.printf(format, __VA_ARGS__))
#else
 #define DEBUG_PRINTF
#endif

//
// WeMos  ESP8266 Use Warning
// D0     GPIO16
// D1     GPIO5   SCL
// D2     GPIO4   SDA
// D3     GPIO0   Must be PULLED HIGH during boot (Pulled up on WeMos board)
// D4     GPIO2   Must be PULLED HIGH during boot (Pulled up on WeMos board)
// D5     GPIO14  SCL
// D6     GPIO12  MISO  
// D7     GPIO13
// D8     GPIO15  Boot mode, must be LOW during flash boot
// A0             Analog

#define RST_PIN         D2  // Wemos D2 (GPIO4)
#define RGB_R_PIN       D6  // Wemos D6 (GPIO12)
#define RGB_G_PIN       D1  // Wemos D1 (GPIO5)
#define RGB_B_PIN       D5  // Wemos D5 (GPIO14)

// Minimun delay between mqtt publish events. Prevents mqtt spam e.g. DSMR 5.0 updates every second!
#define MQTT_TOPIC_UPDATE_RATE_MS  20000

// Local variables
uint32_t cur=0, prev=0;
WiFiManager wifiManager;

typedef enum {
  RED = 0, GREEN, BLUE
} RGB_COLOR_ENUM;

typedef enum {
  ON = 0, OFF
} RGB_STATE_ENUM;

// Application configs struct. 
bool shouldSaveConfig;

#define MQTT_USERNAME_LENGTH       32
#define MQTT_PASSWORD_LENGTH       32
#define MQTT_ID_TOKEN_LENGTH       64
#define MQTT_TOPIC_STRING_LENGTH   64
#define MQTT_REMOTE_HOST_LENGTH   128
#define MQTT_REMOTE_PORT_LENGTH    10
#define P1_BAUDRATE_LENGTH         10

typedef struct {
   char     mqtt_username[MQTT_USERNAME_LENGTH];
   char     mqtt_password[MQTT_PASSWORD_LENGTH];
   char     mqtt_id[MQTT_ID_TOKEN_LENGTH];
   char     mqtt_topic[MQTT_TOPIC_STRING_LENGTH];
   char     mqtt_remote_host[MQTT_REMOTE_HOST_LENGTH];
   char     mqtt_remote_port[MQTT_REMOTE_PORT_LENGTH];
   char     p1_baudrate[P1_BAUDRATE_LENGTH];
} APP_CONFIG_STRUCT;

APP_CONFIG_STRUCT app_config;

// Wifi client used for the MQTT library
WiFiClient mqttWifiClient;

// Only with some dummy values seems to work ... instead of mqttClient();
PubSubClient mqttClient("", 0, mqttWifiClient);
uint32_t mqttTimer = 0; // Time used to reconnect to the mqtt server, when disconnected (#26)

#define P1_TELEGRAM_SIZE   2048

// Datagram P1 buffer 
#define P1_MAX_DATAGRAM_SIZE 2048
char p1_buf[P1_MAX_DATAGRAM_SIZE]; // Complete P1 telegram
char *p1;

// TCP/IP server to implement the P1 datagram provider variables
WiFiServer tcpServer(TCP_DATA_SERVER_PORT); // TCP/IP server
WiFiClient tcpServerClient[TCP_DATA_SERVER_MAX_CLIENTS]; // TCP/IP connected clients

// HTTP Web server variables
#define WEBSERVERDATALENGTH HTTP_SERVER_DATA_LENGTH // Data points that will be stored
#define WEBSERVERDATASAMPLERATE HTTP_SERVER_SAMPLE_RATE // Sample rate to collect the data points in ms
ESP8266WebServer server(80);   // WebServer
bool webServerInitialized = false;
uint16_t webDataPointer = 0; // Pointer to the insert point
uint32_t webserverTimer = 0; // Time used to implement the sample rate
void addWebDataP1(char* p1); // Add data point to the data store from P1 message
void handleRoot(); // Handle root page callback
void handleDataApi(); // Handle data page/api callback
void handleNotFound(); // Handle not found page callback

// Varibles to store the P1 data that is provided to the webpage
char DSMRVersion[5] = "-";
char DSMRTimestamp[14] = "-";
float dataActualPowerConsumption[WEBSERVERDATALENGTH];  // Actual power consumption kW
float dataActualPowerProduction[WEBSERVERDATALENGTH];  // Actual power production kW
float dataEnergyConsumption1[WEBSERVERDATALENGTH]; // Energy consumption 1 kWh
float dataEnergyConsumption2[WEBSERVERDATALENGTH]; // Energy consumption 2 kWh
float dataEnergyProduction1[WEBSERVERDATALENGTH]; // Energy production 1 kWh
float dataEnergyProduction2[WEBSERVERDATALENGTH]; // Energy production 1 kWh

/* Prototype FSM functions. */
void start_pre(void);
void start_heartbeat(void);
void start_post(void);

void idle_pre(void);
void idle_heartbeat(void);
void idle_post(void);

void mqtt_pre(void);
void mqtt_heartbeat(void);
void mqtt_post(void);

/* Define FSM (states, events) */
typedef enum { EV_P1_AVAILABLE, EV_IDLE } ENUM_EVENT;
typedef enum { STATE_START, STATE_IDLE, STATE_MQTT } ENUM_STATE;

/* Define FSM transition */
typedef struct {
   void (*pre)(void);
   void (*heartbeat)(void);
   void (*post)(void);
   ENUM_STATE nextState;
} STATE_TRANSITION_STRUCT;

// SmartMeter reader FSM definition (see statemachine diagram)
//
//        | EV_P1_AVAILABLE  EV_IDLE
// -----------------------------------------------------------------
// START  | -                ILDE   Handle STARTUP      
// IDLE   | MQTT             -      Handle IDLE loop
// MQTT   | -                IDLE   Handle Sending P1 message to broker 
STATE_TRANSITION_STRUCT fsm[3][2] = {
  { 
    {start_pre, start_heartbeat, start_post, STATE_START},
    {start_pre, start_heartbeat, start_post, STATE_IDLE}
  },  // State START
  { 
    {idle_pre, idle_heartbeat, idle_post, STATE_MQTT},
    {idle_pre, idle_heartbeat, idle_post, STATE_IDLE}
  },  // State IDLE
  { 
    {mqtt_pre, mqtt_heartbeat, mqtt_post, STATE_MQTT},
    {mqtt_pre, mqtt_heartbeat, mqtt_post, STATE_IDLE}
  },  // State MQTT
};

// State holder
ENUM_STATE state;
ENUM_EVENT event;

// Heartbeat (polling)
#define HEARTBEAT_UPDATE_INTERVAL_SEC 1000 * 1
uint32_t heartbeat_prev=0, mqtt_throttle_prev = 0;

// P1 statemachine
typedef enum { 
   P1_MSG_S0,
   P1_MSG_S1,
   P1_MSG_S2
} ENUM_P1_MSG_STATE;
ENUM_P1_MSG_STATE p1_msg_state = P1_MSG_S0;

// 
typedef struct {
   char p1_telegram[P1_TELEGRAM_SIZE];
} MEASUREMENT_STRUCT;
MEASUREMENT_STRUCT payload = {""};

// mqtt topic strings: eti-sm
char mqtt_topic[128];

/******************************************************************/
void saveConfigCallback () 
/* 
short:         
inputs:        
outputs: 
notes:         
Version :      DMK, Initial code
*******************************************************************/
{
   shouldSaveConfig = true;
}

/******************************************************************/
void setup() 
/* 
short:         initial setup(), runes only one time
inputs:        
outputs: 
notes:         
Version :      DMK, Initial code
*******************************************************************/
{    
  // Define I/O and attach ISR
  pinMode(RST_PIN, INPUT_PULLUP); // Reset - Use internal pullup
  pinMode(RGB_R_PIN, OUTPUT);     // Red RGB led
  pinMode(RGB_G_PIN, OUTPUT);     // Green RGB led
  pinMode(RGB_B_PIN, OUTPUT);     // Blue RGB led
  
  // Init with red led
  smartLedInit();

  // Say Hello to user
  for(uint8_t idx = 0; idx < 2; idx++ ) {
    smartLedFlash(BLUE);
    delay(150);
  }

  // Setup unique mqtt id and mqtt topic string
  create_unique_mqtt_topic_string(app_config.mqtt_topic);
  create_unigue_mqtt_id(app_config.mqtt_id);
  sprintf(mqtt_topic, MQTT_TOPIC);

  // Perform factory reset switches
  // is pressed during powerup
  if( 0 == digitalRead(RST_PIN) ) {
    wifiManager.resetSettings();
    deleteAppConfig();
    while(0 == digitalRead(RST_PIN)) {
       smartLedFlash(BLUE);
       delay(250);
    }
    ESP.reset();
  }

  // Read config file or generate default
  if( !readAppConfig(&app_config) ) {
    strcpy(app_config.mqtt_username, MQTT_USERNAME);
    strcpy(app_config.mqtt_password, MQTT_PASSWORD);
    strcpy(app_config.mqtt_remote_host, MQTT_REMOTE_HOST);
    strcpy(app_config.mqtt_remote_port, MQTT_REMOTE_PORT);
    strcpy(app_config.p1_baudrate, "115200");
    writeAppConfig(&app_config);
  }

  wifiManager.setMinimumSignalQuality(20);
  wifiManager.setTimeout(300);
  wifiManager.setSaveConfigCallback(saveConfigCallback);
  shouldSaveConfig = false;

  // Adds some parameters to the default webpage
  WiFiManagerParameter wmp_text("<br/>MQTT setting:</br>");
  wifiManager.addParameter(&wmp_text);
  WiFiManagerParameter custom_mqtt_username("mqtt_username", "Username", app_config.mqtt_username, MQTT_USERNAME_LENGTH);
  WiFiManagerParameter custom_mqtt_password("mqtt_password", "Password", app_config.mqtt_password, MQTT_PASSWORD_LENGTH);
  WiFiManagerParameter custom_mqtt_remote_host("mqtt_remote_host", "Host", app_config.mqtt_remote_host, MQTT_REMOTE_HOST_LENGTH);
  WiFiManagerParameter custom_mqtt_remote_port("mqtt_remote_port", "Port", app_config.mqtt_remote_port, MQTT_REMOTE_PORT_LENGTH);
  WiFiManagerParameter custom_p1_baudrate("p1_baudrate", "Baudrate", app_config.p1_baudrate, P1_BAUDRATE_LENGTH);

  wifiManager.addParameter(&custom_mqtt_username);
  wifiManager.addParameter(&custom_mqtt_password);
  wifiManager.addParameter(&custom_mqtt_remote_host);
  wifiManager.addParameter(&custom_mqtt_remote_port);
  wifiManager.addParameter(&custom_p1_baudrate);
  
  // Add the unit ID to the webpage
  char fd_str[128]="<p>Your EMON ID: <b>";
  strcat(fd_str, app_config.mqtt_topic);
  strcat(fd_str, "</b> Make a SCREENSHOT - you will need this info later!</p>");
  WiFiManagerParameter mqqt_topic_text(fd_str);
  wifiManager.addParameter(&mqqt_topic_text);

  // Blue led on. Will go GREEN if WiFi network is available or 
  // stays BLUE when WiFi credentials are needed.
  smartLedColor(BLUE, ON);
  
  if( !wifiManager.autoConnect("ETI EMON config")) {
    delay(1000);
    ESP.reset();
  }  

  //
  // Update config if needed
  //
  if(shouldSaveConfig) {
    strcpy(app_config.mqtt_username, custom_mqtt_username.getValue());
    strcpy(app_config.mqtt_password, custom_mqtt_password.getValue());
    strcpy(app_config.mqtt_remote_host, custom_mqtt_remote_host.getValue());
    strcpy(app_config.mqtt_remote_port, custom_mqtt_remote_port.getValue());
    strcpy(app_config.p1_baudrate, custom_p1_baudrate.getValue());
    writeAppConfig(&app_config);
  }

  // Setup TCP/IP server
  tcpServer.begin();
  
  // Web server initialization
  server.on("/", handleRoot);               // Call the 'handleRoot' function when a client requests URI "/"
  server.on("/data", handleDataApi);        // Call the 'handleDataApi' function when a client requests URI "/data"
  server.onNotFound(handleNotFound);        // When a client requests an unknown URI (i.e. something other than "/"), call function "handleNotFound"
  server.begin();                           // Actually start the server

  // Initialize the data stores with zero
  for ( uint16_t i=0; i < WEBSERVERDATALENGTH; i++ ) {
    dataActualPowerConsumption[i] = 0; // Actual power consumpation kW
    dataActualPowerProduction[i] = 0; // Actual power production kW
    dataEnergyConsumption1[i] = 0; // Energy 1 consumption Kwh
    dataEnergyConsumption2[i] = 0; // Energy 2 consumption kWh
    dataEnergyProduction1[i] = 0; // Energy 1 production kWh
    dataEnergyProduction2[i] = 0; // Energy 2 production kWh
  }

  // Always print config to terminal before swapping serial port
  Serial.begin(115200, SERIAL_8N1);

  Serial.printf("\n");
  Serial.printf("************ DIY Smartmeter KIT********************\n");
  Serial.printf("ESP8266 info\n");
  Serial.printf("\tSDK Version     : %s\n", ESP.getSdkVersion() );
  Serial.printf("\tCore Version    : %s\n", ESP.getCoreVersion().c_str() );
  Serial.printf("\tCore Frequency  : %d Mhz\n", ESP.getCpuFreqMHz());
  Serial.printf("\tLast reset      : %s\n", ESP.getResetReason().c_str() );

  Serial.printf("MQTT settings\n");
  Serial.printf("\tmqtt_username   : %s\n", app_config.mqtt_username);
  Serial.printf("\tmqtt_password   : %s\n", app_config.mqtt_password);
  Serial.printf("\tmqtt_id         : %s\n", app_config.mqtt_id);
  Serial.printf("\tmqtt_topic      : %s\n", mqtt_topic);
  Serial.printf("\tmqtt_remote_host: %s\n", app_config.mqtt_remote_host);
  Serial.printf("\tmqtt_remote_port: %s\n", app_config.mqtt_remote_port);
  Serial.printf("\tIP address      : %s\n", WiFi.localIP().toString().c_str());

  Serial.printf("DSMR settings\n");
  Serial.printf("\tP1 Baudrate     : %s baud\n", app_config.p1_baudrate);

  // Setup mDNS Service
  if ( MDNS.begin("diy_smartmeter") ) { 
    MDNS.addService("http", "tcp", 80);     // Webserver
    MDNS.addService("p1data", "tcp", 3141); // TCP/IP P1 data provider server
    Serial.printf("mDNS\n");
    Serial.printf("\tmDNS URL        : %s\n", "diy_smartmeter.local");
    Serial.printf("\tWeb server      : %s\n", "diy_smartmeter.local:80");
    Serial.printf("\tData server     : %s\n", "diy_smartmeter.local:3141");
  } else {
    Serial.printf("mDNS:   Could not start the mDNS service!\n");
  }

  Serial.printf("***************************************************\n\n");
  Serial.flush();

  // Set P1 port baudrate. DSMR V2 uses 9600 baud. Otherwise 115200 baud
  long baudrate = atol(app_config.p1_baudrate);
  switch(baudrate){
    case 9600:
      Serial.begin(9600, SERIAL_7E1);
      break;

    default:
      Serial.begin(115200, SERIAL_8N1);
      break;
  }

  #ifdef DEBUG
    Serial1.begin(115200, SERIAL_8N1);
    DEBUG_PRINTF("\n\r%s\n\r", "Debug mode ON ..." );
  #endif
 
  // Allow bootloader to connect: do not remove!
  delay(2000);
  
  // Relocate Serial Port
  Serial.swap();
  
  // Initialise FSM
  initFSM(STATE_START, EV_IDLE);
}

/******************************************************************/
void loop()
/* 
short:         loop(), runs forever executing FSM
inputs:        
outputs: 
notes:         MS, Not full implementation of FSM; a lot of logic still in loop()
Version :      DMK, Initial code
*******************************************************************/
{

  // Check for IP connection 
  if( WiFi.status() == WL_CONNECTED) {

    // Handle mqtt, if not connected it uses a timer to reconnect every MQTT_RETRY_TIMEOUT ms. (#26)
    if( !mqttClient.connected() && ( mqttTimer == 0 || millis() > mqttTimer + MQTT_RETRY_TIMEOUT ) ) {
      smartLedFlash(RED); // Added to see when MQTT is not connected (#26: causing a delay of 150ms)
      mqtt_connect();
      //delay(250); #26: removed, while it causes problems for the MDNS, HTTP and TCP server updates
      mqttTimer = millis(); // Set timer to reconnect over MQTT_RETRY_TIMEOUT ms (#26)

    } else {
      // Handle MQTT loop
      mqttClient.loop();
    }

    // Handle mDNS service
    MDNS.update();

    // Handle HTTP web server
    server.handleClient(); // Listen for HTTP requests from clients

    // Handle the TCP data server clients
    uint8_t i = 0;
    bool foundOpenWiFiClient = false;
    WiFiClient client = tcpServer.accept();
    if (client) { // we have a new client
      while ( !foundOpenWiFiClient && i < TCP_DATA_SERVER_MAX_CLIENTS ) {
        if ( !tcpServerClient[i].connected() ) {
          tcpServerClient[i] = client;
          tcpServerClient[i].setNoDelay(true);
          char t[] = "DIY Smartmeter P1\n";
          tcpServerClient[i].write(t, strlen(t));
          foundOpenWiFiClient = true;
        }
        i++;
      }

      if ( !foundOpenWiFiClient ) { // No client found, all clients are already connected
        char t[] = "DIY Smartmeter P1 - too many clients connected.\n";
        client.write(t, strlen(t));
        client.stop();
      }      
    }

  }

  // Capture P1 messages. If P1 msg is available raise MQTT event
  if( true == capture_p1() ) {
    if ( millis() > webserverTimer + WEBSERVERDATASAMPLERATE ) {
      addWebDataP1(p1_buf);
      webserverTimer = millis();
    }
    for ( uint8_t i=0; i < TCP_DATA_SERVER_MAX_CLIENTS; i++ ) {
      if ( tcpServerClient[i].connected() ) { // Send the P1 data to the connected client
        tcpServerClient[i].write(p1_buf, strlen(p1_buf));
      }
    }
    raiseEvent(EV_P1_AVAILABLE);
  }

  // 
  // Handle heartbeat (Ticker.h causes crashes)
  //
  uint32_t heartbeat_cur = millis();
  uint32_t heartbeat_elapsed = heartbeat_cur - heartbeat_prev;
  if( heartbeat_elapsed >= HEARTBEAT_UPDATE_INTERVAL_SEC ) {
    
    //
    heartbeat_prev = heartbeat_cur; 
    
    // Call the heartbeat fp
    if( fsm[state][event].heartbeat != NULL) {
      fsm[state][event].heartbeat();
    } 
  }
}


/******************************************************************
*
* MQTT section
*
******************************************************************/

/******************************************************************/
void mqtt_callback(char* topic, byte* payload, unsigned int length)
/* 
short   : mqtt callback                  
inputs  :        
outputs : 
notes   :         
Version : DMK, Initial code
*******************************************************************/
{
}

/******************************************************************/
void mqtt_connect() 
/* 
short:      Connect to MQTT server UNSECURE
inputs:        
outputs: 
notes:         
Version :   DMK, Initial code
*******************************************************************/
{
  char *host = app_config.mqtt_remote_host;
  int port = atoi(app_config.mqtt_remote_port);
  
  mqttClient.setClient(mqttWifiClient);
  mqttClient.setServer(host, port );
  mqttClient.setBufferSize(MQTT_MSGBUF_SIZE);
  if(mqttClient.connect(app_config.mqtt_id, app_config.mqtt_username, app_config.mqtt_password)){

    // Subscribe to mqtt topic
    mqttClient.subscribe(mqtt_topic);

    // Set callback
    mqttClient.setCallback(mqtt_callback);

    // Set timer to zero (#26)
    mqttTimer = 0;

    DEBUG_PRINTF("%s: MQTT connected to %s:%d\n", __FUNCTION__, host, port);
  } else {
    DEBUG_PRINTF("%s: MQTT connection ERROR (%s:%d)\n", __FUNCTION__, host, port);
  }
}

/******************************************************************/
void create_unique_mqtt_topic_string(char *topic_string)
/* 
short:      Construct unique mqtt_signature    
inputs:        
outputs: 
notes:         
Version :   DMK, Initial code
*******************************************************************/
{
   char tmp[30];
   strcpy(topic_string,"EMON19V01");
   sprintf(tmp,"-%06X",ESP.getChipId());
   strcat(topic_string,tmp);
   sprintf(tmp,"-%06X",ESP.getFlashChipId()); 
   strcat(topic_string,tmp);
}

/******************************************************************/
void create_unigue_mqtt_id(char *signature)
/* 
short:      Construct unique mqtt_signature    
inputs:        
outputs: 
notes:         
Version :   DMK, Initial code
*******************************************************************/
{
   char tmp[30];
   strcpy(signature,"2019-ETI-EMON");
   strcat(signature,"-V01");
   sprintf(tmp,"-%06X",ESP.getChipId());
   strcat(signature,tmp);
   sprintf(tmp,"-%06X",ESP.getFlashChipId()); 
   strcat(signature,tmp);
}


/******************************************************************/
/*
 * Application signature and config
 */
/******************************************************************/
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

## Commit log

2019-08-21 initial version: add the initial version to git
    The initial version as produced.
    [SmartMeter.kicad_pcb, SmartMeter.sch, SmartMeter_bom.xlsx]
2019-08-29 hardware: update schematics + PCB to version 2.0
    Update the schematics and layout to v2.0. The pulse counter using a
    TLC555 has been removed, together with the LDR and blue status LED. An
    RGB (common anode) status LED has been added to the board.
    [SmartMeter.kicad_pcb, SmartMeter.sch]
2019-09-04 pcb: update PCB trace
    Reduce faults/errors by increasing the spacing between traces and/or
    components.
    [SmartMeter.kicad_pcb]
2019-09-04 FInal pcb review, created gerber for production
    [SmartMeter.kicad_pcb, SmartMeter.sch, SmartMeter_bom.xlsx]
2019-09-05 pcb: move bottom right mounting hole
    Move the bottom right mounting hole. Top left and bottom right mounting
    holes are now mirrored from each other.
    [SmartMeter.kicad_pcb]
2019-09-19 Work in progress. Added software initial version
    [SmartMeter_bom.xlsx]
2019-09-19 Added Gerber and drill files to ignore
2019-09-27 Implemented statemachine
    [SmartMeter_bom.xlsx]
2019-10-03 Added RGB led suport functions
2019-10-06 Fixed few bug RGB led discovered during testing with real hardware.
    [sm-esp8266.ino]
2019-10-11 Fixed I/O port define (4 -> D4). Reset Wifi is working fine now
    [sm-esp8266.ino]
2020-02-02 Fixed I/O pinning
    [SmartMeterV2.sch]
2020-02-06 Updated program flow. Adapted to latest libraries. Test exhaustively config settings (factory reset and user settings)
    [sm-esp8266.ino]
2021-12-24 Added hardware version 2, still in development
    [SmartMeter BOM.xlsx, SmartMeter.kicad_pcb, SmartMeter.sch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]
2021-12-24 Added some installation information to get started with the Arduino IDE for people that do not have experience yet.
2021-12-24 Reorganized the repo, so things are easieer to be found
    [SmartMeter BOM.xlsx, SmartMeter.kicad_pcb, SmartMeter.sch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]
2021-12-24 Deleted the hardware versions and moved it to the Hardwware folder.
    [SmartMeter BOM.xlsx, SmartMeter.kicad_pcb, SmartMeter.sch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]
2021-12-24 Added the new hardware schematics to the documentation
2021-12-30 Added the new images for the new soldering of the new hardware version
2022-01-12 Cleaned and updated Arduino to latest libraries. Fixed manual setting buffersize in pubsubclient. Removed out out date platform/Io environment. Add easy mqtt setting in seperate config file.
    Cleaned and updated Arduino to latest libraries. Fixed manual setting buffersize in pubsubclient. Removed out out date platform/Io environment. Add easy mqtt setting in seperate config file.
    [sm-esp8266.ino]
2022-10-02 Updated PlatformIO and added error flash led to ino
    [sm-esp8266.ino]
2024-11-09 Updated the correct version
    [SmartMeter BOM.xlsx, SmartMeter.kicad_pcb, SmartMeter.sch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]
2024-12-01 Added web server and made some fixes
    [sm-esp8266.ino]
2024-12-01 Small changes to fix the logics of the web page
    [sm-esp8266.ino]
2025-01-31 Fixed MDNS, it was not working due to not calling update() in the loop
    [sm-esp8266.ino]
2025-01-31 Update sm-esp8266.ino
    Fixed the MDNS problem of not working.
    [sm-esp8266.ino]
2025-02-01 Added power production
2025-02-01 Type fixed in mDNS
    [sm-esp8266.ino]
2025-03-30 Migrated SPIFSS to LittleFS, ArduinoJSON version 6 to 7 and updated libraries
2025-03-30 Some minor fixes in serial output
    [sm-esp8266.ino]
2025-07-26 Added draft version to solve the problem. Requires testing before merging
    [sm-esp8266.ino]
2025-07-26 Finalizing solution to solve problem when MQTT server is not responding
    [sm-esp8266.ino]
2025-08-12 Added different logo files for the smartmeter and updated the README.md according to the current state.
